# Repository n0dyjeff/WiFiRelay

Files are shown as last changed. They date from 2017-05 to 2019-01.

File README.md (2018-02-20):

# WiFiRelay - Wifi controlled dual relay
Dual relay controlled via WiFi. Uses ESP-07 module to allow external WiFi antenna.

### Motivation
This project was motivated by a desire to control my pool lights from my home automation system. I first attempted to use a Sonoff wifi controlled module with a custom hacked firmware. This would have been successful except that the unit is housed in the metallic NEMA enclosure for the pool control hardware which acted as a Faraday cage, preventing the wifi signal from reaching the Sonoff unit.

This project uses an ESP-07 module containing the ubiquitous ESP8266. The advantage of the ESP-07S is that in addition to a WiFi antenna printed onto the PC board, it has a connector allowing a coax to an external antenna, which can then be mounted outside the enclosure.

### Features
- Built in power supply allows direct connection to AC mains (85 ~ 305VAC). No external adapter required.
- Two isolated, independantly controlled, normally open relay contacts rated at 10 amps each.
- Connector for external WiFi antenna allows unit to be mounted within a metal enclosure.
- Over the air software updates.
- Wifi control via MQTT subscription.

### Software
(https://github.com/n0dyjeff/WifiRelay-Tasmota)

### Availability
All the documentation is here, but if you're not interested in building your own, I've built up a few of these and offered them on [Amazon](https://www.amazon.com/N0DY-WiFi-Controlled-Dual-Relay/dp/B072MKV8ZM), [ebay](http://www.ebay.com/itm/NEW-Web-Controlled-Dual-Relay-120-240-V-Smart-Home-Internal-External-Antenna-/152649721279), and [Tindie](https://www.tindie.com/products/n0dyjeff/wi-fi-controlled-dual-relay-wext-antenna-jack/). It's also available direct from my via my web site, [N0DY Electronics](https://www.n0dy.com).

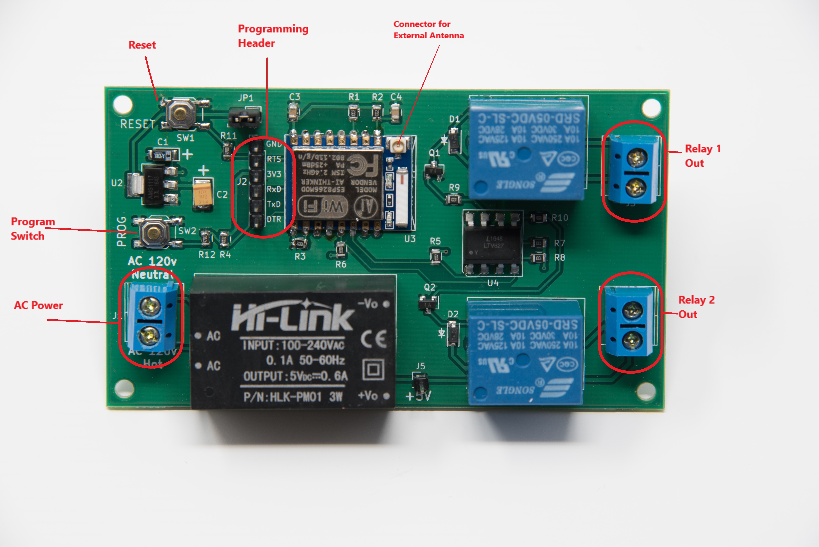
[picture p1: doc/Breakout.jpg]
Relay Board


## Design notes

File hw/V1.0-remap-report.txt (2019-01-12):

Info: Backing up file “C:\Users\jeff.DAVIS\Documents\Projects\WiFiRelay\hw\sym-lib-table” to file “C:\Users\jeff.DAVIS\Documents\Projects\WiFiRelay\hw\rescue-backup\sym-lib-table-2019-01-12-09-16-42”.
Info: Backing up file “C:\Users\jeff.DAVIS\Documents\Projects\WiFiRelay\hw\WifiRelay.sch” to file “C:\Users\jeff.DAVIS\Documents\Projects\WiFiRelay\hw\rescue-backup\WifiRelay-2019-01-12-09-16-42.sch”.
Info: Backing up file “C:\Users\jeff.DAVIS\Documents\Projects\WiFiRelay\hw\WifiRelay.pro” to file “C:\Users\jeff.DAVIS\Documents\Projects\WiFiRelay\hw\rescue-backup\WifiRelay-2019-01-12-09-16-42.pro”.
Info: Backing up file “C:\Users\jeff.DAVIS\Documents\Projects\WiFiRelay\hw\WifiRelay-cache.lib” to file “C:\Users\jeff.DAVIS\Documents\Projects\WiFiRelay\hw\rescue-backup\WifiRelay-cache-2019-01-12-09-16-42.lib”.
Info: Backing up file “C:\Users\jeff.DAVIS\Documents\Projects\WiFiRelay\hw\WifiRelay-rescue.lib” to file “C:\Users\jeff.DAVIS\Documents\Projects\WiFiRelay\hw\rescue-backup\WifiRelay-rescue-2019-01-12-09-16-42.lib”.
Info: Backing up file “C:\Users\jeff.DAVIS\Documents\Projects\WiFiRelay\hw\WifiRelay-rescue.dcm” to file “C:\Users\jeff.DAVIS\Documents\Projects\WiFiRelay\hw\rescue-backup\WifiRelay-rescue-2019-01-12-09-16-42.dcm”.
Info: Adding library “power1”, file “C:\Users\jeff.DAVIS\Documents\KiCadLibraries\library\power.lib” to project symbol library table.
Info: Adding library “device”, file “C:\Users\jeff.DAVIS\Documents\KiCadLibraries\library\device.lib” to project symbol library table.
Info: Adding library “transistors”, file “C:\Users\jeff.DAVIS\Documents\KiCadLibraries\library\transistors.lib” to project symbol library table.
Info: Adding library “conn”, file “C:\Users\jeff.DAVIS\Documents\KiCadLibraries\library\conn.lib” to project symbol library table.
Info: Adding library “linear”, file “C:\Users\jeff.DAVIS\Documents\KiCadLibraries\library\linear.lib” to project symbol library table.
Info: Adding library “regul”, file “C:\Users\jeff.DAVIS\Documents\KiCadLibraries\library\regul.lib” to project symbol library table.
Info: Adding library “74xx1”, file “C:\Users\jeff.DAVIS\Documents\KiCadLibraries\library\74xx.lib” to project symbol library table.
Info: Adding library “cmos4000”, file “C:\Users\jeff.DAVIS\Documents\KiCadLibraries\library\cmos4000.lib” to project symbol library table.
Info: Adding library “adc-dac”, file “C:\Users\jeff.DAVIS\Documents\KiCadLibraries\library\adc-dac.lib” to project symbol library table.
Info: Adding library “memory”, file “C:\Users\jeff.DAVIS\Documents\KiCadLibraries\library\memory.lib” to project symbol library table.
Info: Adding library “xilinx”, file “C:\Users\jeff.DAVIS\Documents\KiCadLibraries\library\xilinx.lib” to project symbol library table.
Info: Adding library “microcontrollers”, file “C:\Users\jeff.DAVIS\Documents\KiCadLibraries\library\microcontrollers.lib” to project symbol library table.
Info: Adding library “dsp”, file “C:\Users\jeff.DAVIS\Documents\KiCadLibraries\library\dsp.lib” to project symbol library table.
Info: Adding library “microchip”, file “C:\Users\jeff.DAVIS\Documents\KiCadLibraries\library\microchip.lib” to project symbol library table.
Info: Adding library “analog_switches”, file “C:\Users\jeff.DAVIS\Documents\KiCadLibraries\library\analog_switches.lib” to project symbol library table.
Info: Adding library “motorola”, file “C:\Users\jeff.DAVIS\Documents\KiCadLibraries\library\motorola.lib” to project symbol library table.
Info: Adding library “texas”, file “C:\Users\jeff.DAVIS\Documents\KiCadLibraries\library\texas.lib” to project symbol library table.
Info: Adding library “intel”, file “C:\Users\jeff.DAVIS\Documents\KiCadLibraries\library\intel.lib” to project symbol library table.
Info: Adding library “audio”, file “C:\Users\jeff.DAVIS\Documents\KiCadLibraries\library\audio.lib” to project symbol library table.
Info: Adding library “interface”, file “C:\Users\jeff.DAVIS\Documents\KiCadLibraries\library\interface.lib” to project symbol library table.
Info: Adding library “digital-audio”, file “C:\Users\jeff.DAVIS\Documents\KiCadLibraries\library\digital-audio.lib” to project symbol library table.
Info: Adding library “philips”, file “C:\Users\jeff.DAVIS\Documents\KiCadLibraries\library\philips.lib” to project symbol library table.
Info: Adding library “display”, file “C:\Users\jeff.DAVIS\Documents\KiCadLibraries\library\display.lib” to project symbol library table.
Info: Adding library “cypress”, file “C:\Users\jeff.DAVIS\Documents\KiCadLibraries\library\cypress.lib” to project symbol library table.
Info: Adding library “siliconi”, file “C:\Users\jeff.DAVIS\Documents\KiCadLibraries\library\siliconi.lib” to project symbol library table.
Info: Adding library “opto”, file “C:\Users\jeff.DAVIS\Documents\KiCadLibraries\library\opto.lib” to project symbol library table.
Info: Adding library “atmel”, file “C:\Users\jeff.DAVIS\Documents\KiCadLibraries\library\atmel.lib” to project symbol library table.
Info: Adding library “contrib”, file “C:\Users\jeff.DAVIS\Documents\KiCadLibraries\library\contrib.lib” to project symbol library table.
Info: Adding library “valves”, file “C:\Users\jeff.DAVIS\Documents\KiCadLibraries\library\valves.lib” to project symbol library table.
Info: Adding library “relays”, file “C:\Users\jeff.DAVIS\Documents\KiCadLibraries\library\relays.lib” to project symbol library table.
Info: Adding library “switches”, file “C:\Users\jeff.DAVIS\Documents\KiCadLibraries\library\switches.lib” to project symbol library table.
Info: Adding library “leds”, file “C:\Users\jeff.DAVIS\Documents\KiCadLibraries\library\leds.lib” to project symbol library table.
Info: Adding library “ESP8266”, file “C:\Users\jeff.DAVIS\Documents\Github\kicad-ESP8266\ESP8266.lib” to project symbol library table.
Info: Adding library “WifiRelay”, file “${KIPRJMOD}/WifiRelay.lib” to project symbol library table.
Symbol “CONN_01X06” mapped to symbol library “conn”.
Symbol “GND” mapped to symbol library “power1”.
Symbol “+3.3V” mapped to symbol library “power1”.
Symbol “+5V” mapped to symbol library “power1”.
Symbol “GND” mapped to symbol library “power1”.
Symbol “+5V” mapped to symbol library “power1”.
Symbol “+3.3V” mapped to symbol library “power1”.
Symbol “+5V” mapped to symbol library “power1”.
Symbol “CONN_01X02” mapped to symbol library “conn”.
Symbol “1N4148” mapped to symbol library “WifiRelay”.
Symbol “GND” mapped to symbol library “power1”.
Symbol “+5V” mapped to symbol library “power1”.
Symbol “+3.3V” mapped to symbol library “power1”.
Symbol “+5V” mapped to symbol library “power1”.
Symbol “+3.3V” mapped to symbol library “power1”.
Symbol “+3.3V” mapped to symbol library “power1”.
Symbol “GND” mapped to symbol library “power1”.
Symbol “GND” mapped to symbol library “power1”.
Symbol “GND” mapped to symbol library “power1”.
Symbol “C” mapped to symbol library “device”.
Symbol “GND” mapped to symbol library “power1”.
Symbol “+3.3V” mapped to symbol library “power1”.
Symbol “+3.3V” mapped to symbol library “power1”.
Symbol “PWR_FLAG” mapped to symbol library “power1”.
Symbol “PWR_FLAG” mapped to symbol library “power1”.
Symbol “R” mapped to symbol library “device”.
Symbol “R” mapped to symbol library “device”.
Symbol “R” mapped to symbol library “device”.
Symbol “R” mapped to symbol library “device”.
Symbol “MMSS8050-H” mapped to symbol library “transistors”.
Symbol “MMSS8050-H” mapped to symbol library “transistors”.
Symbol “1N4148” mapped to symbol library “WifiRelay”.
Symbol “CONN_01X02” mapped to symbol library “conn”.
Symbol “CONN_01X02” mapped to symbol library “conn”.
Symbol “IRM-02-5” mapped to symbol library “WifiRelay”.
Symbol “LM1117-3.3” mapped to symbol library “regul”.
Symbol “CP” mapped to symbol library “device”.
Symbol “CP” mapped to symbol library “device”.
Symbol “R” mapped to symbol library “device”.
Symbol “R” mapped to symbol library “device”.
Symbol “R” mapped to symbol library “device”.
Symbol “R” mapped to symbol library “device”.
Symbol “R” mapped to symbol library “device”.
Symbol “R” mapped to symbol library “device”.
Symbol “TCMT1100” mapped to symbol library “WifiRelay”.
Symbol “TCMT1100” mapped to symbol library “WifiRelay”.
Symbol “G5Q-1A” mapped to symbol library “relays”.
Symbol “G5Q-1A” mapped to symbol library “relays”.
Symbol “SW_Push” mapped to symbol library “switches”.
Symbol “SW_Push” mapped to symbol library “switches”.
Symbol “R” mapped to symbol library “device”.
Symbol “R” mapped to symbol library “device”.
Symbol “GND” mapped to symbol library “power1”.
Symbol “GND” mapped to symbol library “power1”.
Symbol “C” mapped to symbol library “device”.
Symbol “Jumper” mapped to symbol library “device”.
Symbol “PWR_FLAG” mapped to symbol library “power1”.
Symbol “LED” mapped to symbol library “device”.
Symbol “LED” mapped to symbol library “device”.
Symbol “LED” mapped to symbol library “device”.
Symbol “R” mapped to symbol library “device”.
Symbol “GND” mapped to symbol library “power1”.
Symbol “ESP-07v2” mapped to symbol library “ESP8266”.
Info: Symbol library table mapping complete!

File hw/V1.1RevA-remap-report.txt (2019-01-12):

Info: Backing up file “C:\Users\jeff.DAVIS\Documents\Projects\WiFiRelay\hw\sym-lib-table” to file “C:\Users\jeff.DAVIS\Documents\Projects\WiFiRelay\hw\rescue-backup\sym-lib-table-2019-01-12-10-57-47”.
Info: Backing up file “C:\Users\jeff.DAVIS\Documents\Projects\WiFiRelay\hw\WifiRelay.sch” to file “C:\Users\jeff.DAVIS\Documents\Projects\WiFiRelay\hw\rescue-backup\WifiRelay-2019-01-12-10-57-47.sch”.
Info: Backing up file “C:\Users\jeff.DAVIS\Documents\Projects\WiFiRelay\hw\WifiRelay.pro” to file “C:\Users\jeff.DAVIS\Documents\Projects\WiFiRelay\hw\rescue-backup\WifiRelay-2019-01-12-10-57-47.pro”.
Info: Backing up file “C:\Users\jeff.DAVIS\Documents\Projects\WiFiRelay\hw\WifiRelay-cache.lib” to file “C:\Users\jeff.DAVIS\Documents\Projects\WiFiRelay\hw\rescue-backup\WifiRelay-cache-2019-01-12-10-57-47.lib”.
Info: Backing up file “C:\Users\jeff.DAVIS\Documents\Projects\WiFiRelay\hw\WifiRelay-rescue.lib” to file “C:\Users\jeff.DAVIS\Documents\Projects\WiFiRelay\hw\rescue-backup\WifiRelay-rescue-2019-01-12-10-57-47.lib”.
Info: Backing up file “C:\Users\jeff.DAVIS\Documents\Projects\WiFiRelay\hw\WifiRelay-rescue.dcm” to file “C:\Users\jeff.DAVIS\Documents\Projects\WiFiRelay\hw\rescue-backup\WifiRelay-rescue-2019-01-12-10-57-47.dcm”.
Info: Adding library “power1”, file “C:\Users\jeff.DAVIS\Documents\KiCadLibraries\library\power.lib” to project symbol library table.
Info: Adding library “device”, file “C:\Users\jeff.DAVIS\Documents\KiCadLibraries\library\device.lib” to project symbol library table.
Info: Adding library “transistors”, file “C:\Users\jeff.DAVIS\Documents\KiCadLibraries\library\transistors.lib” to project symbol library table.
Info: Adding library “conn”, file “C:\Users\jeff.DAVIS\Documents\KiCadLibraries\library\conn.lib” to project symbol library table.
Info: Adding library “linear”, file “C:\Users\jeff.DAVIS\Documents\KiCadLibraries\library\linear.lib” to project symbol library table.
Info: Adding library “regul”, file “C:\Users\jeff.DAVIS\Documents\KiCadLibraries\library\regul.lib” to project symbol library table.
Info: Adding library “74xx1”, file “C:\Users\jeff.DAVIS\Documents\KiCadLibraries\library\74xx.lib” to project symbol library table.
Info: Adding library “cmos4000”, file “C:\Users\jeff.DAVIS\Documents\KiCadLibraries\library\cmos4000.lib” to project symbol library table.
Info: Adding library “adc-dac”, file “C:\Users\jeff.DAVIS\Documents\KiCadLibraries\library\adc-dac.lib” to project symbol library table.
Info: Adding library “memory”, file “C:\Users\jeff.DAVIS\Documents\KiCadLibraries\library\memory.lib” to project symbol library table.
Info: Adding library “xilinx”, file “C:\Users\jeff.DAVIS\Documents\KiCadLibraries\library\xilinx.lib” to project symbol library table.
Info: Adding library “microcontrollers”, file “C:\Users\jeff.DAVIS\Documents\KiCadLibraries\library\microcontrollers.lib” to project symbol library table.
Info: Adding library “dsp”, file “C:\Users\jeff.DAVIS\Documents\KiCadLibraries\library\dsp.lib” to project symbol library table.
Info: Adding library “microchip”, file “C:\Users\jeff.DAVIS\Documents\KiCadLibraries\library\microchip.lib” to project symbol library table.
Info: Adding library “analog_switches”, file “C:\Users\jeff.DAVIS\Documents\KiCadLibraries\library\analog_switches.lib” to project symbol library table.
Info: Adding library “motorola”, file “C:\Users\jeff.DAVIS\Documents\KiCadLibraries\library\motorola.lib” to project symbol library table.
Info: Adding library “texas”, file “C:\Users\jeff.DAVIS\Documents\KiCadLibraries\library\texas.lib” to project symbol library table.
Info: Adding library “intel”, file “C:\Users\jeff.DAVIS\Documents\KiCadLibraries\library\intel.lib” to project symbol library table.
Info: Adding library “audio”, file “C:\Users\jeff.DAVIS\Documents\KiCadLibraries\library\audio.lib” to project symbol library table.
Info: Adding library “interface”, file “C:\Users\jeff.DAVIS\Documents\KiCadLibraries\library\interface.lib” to project symbol library table.
Info: Adding library “digital-audio”, file “C:\Users\jeff.DAVIS\Documents\KiCadLibraries\library\digital-audio.lib” to project symbol library table.
Info: Adding library “philips”, file “C:\Users\jeff.DAVIS\Documents\KiCadLibraries\library\philips.lib” to project symbol library table.
Info: Adding library “display”, file “C:\Users\jeff.DAVIS\Documents\KiCadLibraries\library\display.lib” to project symbol library table.
Info: Adding library “cypress”, file “C:\Users\jeff.DAVIS\Documents\KiCadLibraries\library\cypress.lib” to project symbol library table.
Info: Adding library “siliconi”, file “C:\Users\jeff.DAVIS\Documents\KiCadLibraries\library\siliconi.lib” to project symbol library table.
Info: Adding library “opto”, file “C:\Users\jeff.DAVIS\Documents\KiCadLibraries\library\opto.lib” to project symbol library table.
Info: Adding library “atmel”, file “C:\Users\jeff.DAVIS\Documents\KiCadLibraries\library\atmel.lib” to project symbol library table.
Info: Adding library “contrib”, file “C:\Users\jeff.DAVIS\Documents\KiCadLibraries\library\contrib.lib” to project symbol library table.
Info: Adding library “valves”, file “C:\Users\jeff.DAVIS\Documents\KiCadLibraries\library\valves.lib” to project symbol library table.
Info: Adding library “relays”, file “C:\Users\jeff.DAVIS\Documents\KiCadLibraries\library\relays.lib” to project symbol library table.
Info: Adding library “switches”, file “C:\Users\jeff.DAVIS\Documents\KiCadLibraries\library\switches.lib” to project symbol library table.
Info: Adding library “leds”, file “C:\Users\jeff.DAVIS\Documents\KiCadLibraries\library\leds.lib” to project symbol library table.
Info: Adding library “ESP8266”, file “C:\Users\jeff.DAVIS\Documents\GitHub\kicad-ESP8266\ESP8266.lib” to project symbol library table.
Info: Adding library “WifiRelay”, file “${KIPRJMOD}/WifiRelay.lib” to project symbol library table.
Symbol “CONN_01X06” mapped to symbol library “conn”.
Symbol “GND” mapped to symbol library “power1”.
Symbol “+5V” mapped to symbol library “power1”.
Symbol “GND” mapped to symbol library “power1”.
Symbol “+5V” mapped to symbol library “power1”.
Symbol “+3.3V” mapped to symbol library “power1”.
Symbol “+5V” mapped to symbol library “power1”.
Symbol “CONN_01X02” mapped to symbol library “conn”.
Symbol “1N4148” mapped to symbol library “WifiRelay”.
Symbol “GND” mapped to symbol library “power1”.
Symbol “+5V” mapped to symbol library “power1”.
Symbol “+3.3V” mapped to symbol library “power1”.
Symbol “+5V” mapped to symbol library “power1”.
Symbol “+3.3V” mapped to symbol library “power1”.
Symbol “GND” mapped to symbol library “power1”.
Symbol “GND” mapped to symbol library “power1”.
Symbol “GND” mapped to symbol library “power1”.
Symbol “C” mapped to symbol library “device”.
Symbol “GND” mapped to symbol library “power1”.
Symbol “+3.3V” mapped to symbol library “power1”.
Symbol “+3.3V” mapped to symbol library “power1”.
Symbol “PWR_FLAG” mapped to symbol library “power1”.
Symbol “PWR_FLAG” mapped to symbol library “power1”.
Symbol “R” mapped to symbol library “device”.
Symbol “R” mapped to symbol library “device”.
Symbol “R” mapped to symbol library “device”.
Symbol “R” mapped to symbol library “device”.
Symbol “MMSS8050-H” mapped to symbol library “transistors”.
Symbol “MMSS8050-H” mapped to symbol library “transistors”.
Symbol “1N4148” mapped to symbol library “WifiRelay”.
Symbol “CONN_01X02” mapped to symbol library “conn”.
Symbol “CONN_01X02” mapped to symbol library “conn”.
Symbol “IRM-02-5” mapped to symbol library “WifiRelay”.
Symbol “LM1117-3.3” mapped to symbol library “regul”.
Symbol “CP” mapped to symbol library “device”.
Symbol “CP” mapped to symbol library “device”.
Symbol “R” mapped to symbol library “device”.
Symbol “R” mapped to symbol library “device”.
Symbol “R” mapped to symbol library “device”.
Symbol “R” mapped to symbol library “device”.
Symbol “R” mapped to symbol library “device”.
Symbol “R” mapped to symbol library “device”.
Symbol “SW_Push” mapped to symbol library “switches”.
Symbol “SW_Push” mapped to symbol library “switches”.
Symbol “R” mapped to symbol library “device”.
Symbol “R” mapped to symbol library “device”.
Symbol “GND” mapped to symbol library “power1”.
Symbol “GND” mapped to symbol library “power1”.
Symbol “C” mapped to symbol library “device”.
Symbol “ESP-07v2” mapped to symbol library “ESP8266”.
Symbol “Songle-SRD-05VDC-SL-C” mapped to symbol library “WifiRelay”.
Symbol “Songle-SRD-05VDC-SL-C” mapped to symbol library “WifiRelay”.
Symbol “+3.3V” mapped to symbol library “power1”.
Symbol “PC827” mapped to symbol library “opto”.
Symbol “PC827” mapped to symbol library “opto”.
Symbol “TEST_1P” mapped to symbol library “conn”.
Symbol “TEST_1P” mapped to symbol library “conn”.
Symbol “Jumper_Dual” mapped to symbol library “WifiRelay”.
Symbol “PWR_FLAG” mapped to symbol library “power1”.
Info: Symbol library table mapping complete!

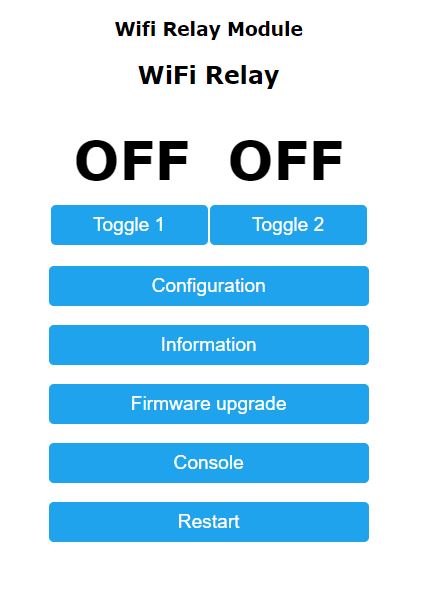
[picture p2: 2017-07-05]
doc/Main Menu.JPG

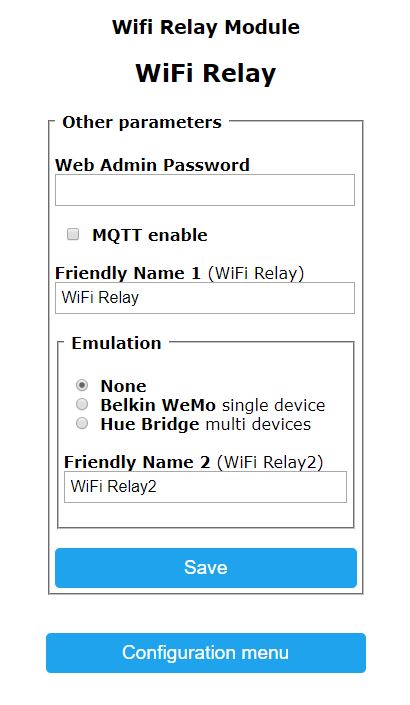
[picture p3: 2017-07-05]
doc/MQTT Enable.jpg

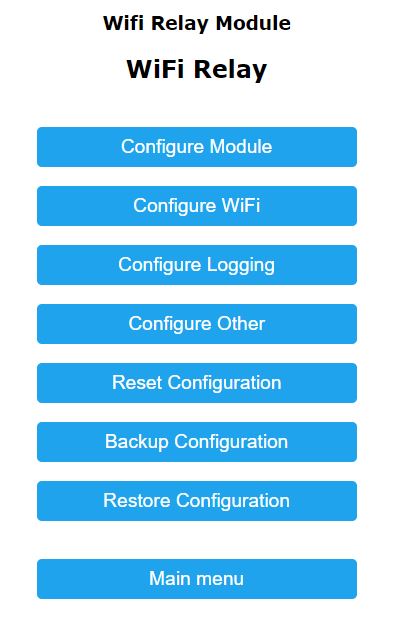
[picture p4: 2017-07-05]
doc/Configuration Menu.jpg

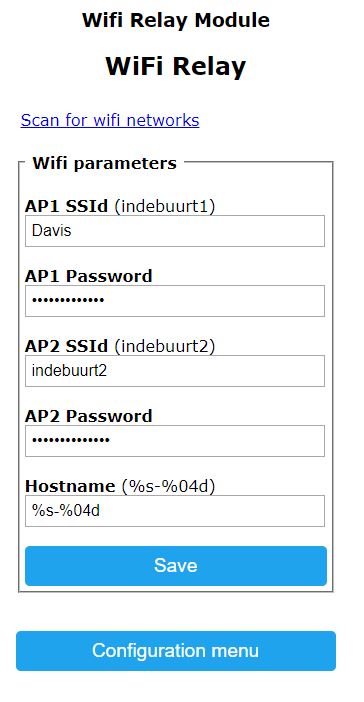
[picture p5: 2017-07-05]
doc/Wifi Menu.JPG

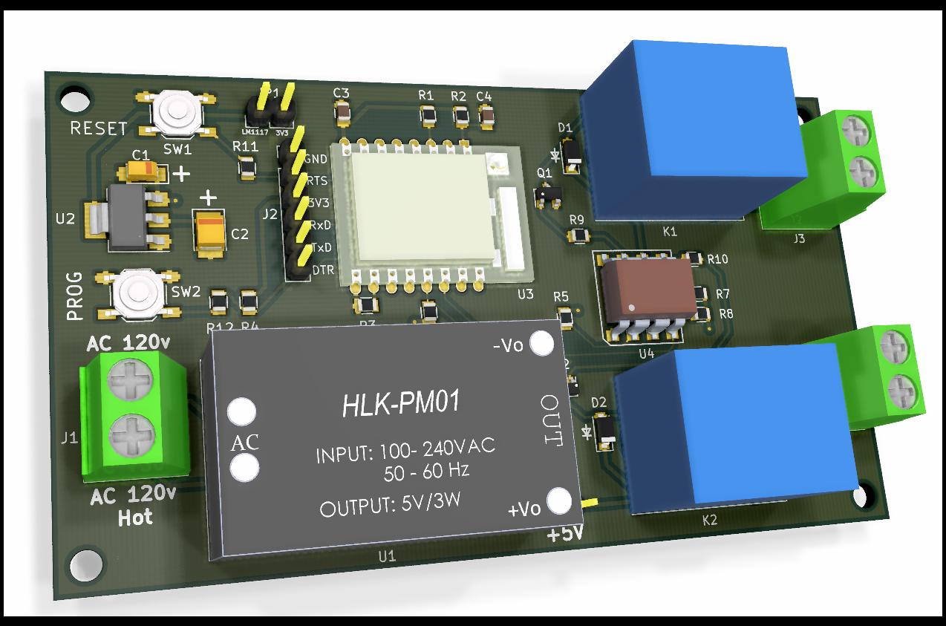
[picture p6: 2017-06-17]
hw/WifiRelay.jpg

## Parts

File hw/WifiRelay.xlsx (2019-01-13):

Source: | C:\Users\jeff.DAVIS\Documents\Projects\WiFiRelay\hw\WifiRelay.sch
Date: | 2019-12-01 16:21
Tool: | Eeschema (5.0.2)-1
Component Count: | 35
Ref | Value | Footprint | Datasheet | Manufacturer | Vendor
C1 | 10 uF | Capacitors_Tantalum_SMD:CP_Tantalum_Case-A_EIA-3216-18_Reflow | http://www.vishay.com/docs/40002/293d.pdf
C2 | 100 uF | Capacitors_Tantalum_SMD:CP_Tantalum_Case-B_EIA-3528-21_Reflow | http://www.vishay.com/docs/40156/tl8.pdf
C3 | 100nF | Capacitors_SMD:C_0805 | http://www.mouser.com/ds/2/212/KEM_C1002_X7R_SMD-357932.pdf
C4 | 100nF | Capacitors_SMD:C_0805 | http://www.mouser.com/ds/2/212/KEM_C1002_X7R_SMD-357932.pdf
D1 | 1N4148 | Diodes_SMD:D_SOD-123 | https://www.diodes.com/assets/Datasheets/ds30086.pdf
D2 | 1N4148 | Diodes_SMD:D_SOD-123 | https://www.diodes.com/assets/Datasheets/ds30086.pdf
J1 | CONN_01X02 | Connectors_Terminal_Blocks:TerminalBlock_Pheonix_MKDS1.5-2pol
J2 | CONN_01X06 | Pin_Headers:Pin_Header_Straight_1x06_Pitch2.54mm
J3 | CONN_01X02 | Connectors_Terminal_Blocks:TerminalBlock_Pheonix_MKDS1.5-2pol
J4 | CONN_01X02 | Connectors_Terminal_Blocks:TerminalBlock_Pheonix_MKDS1.5-2pol
J5 | TEST_1P | Pin_Headers:Pin_Header_Straight_1x01_Pitch2.54mm
J6 | TEST_1P | Pin_Headers:Pin_Header_Straight_1x01_Pitch2.54mm
JP1 | Jumper_Dual | Pin_Headers:Pin_Header_Straight_1x03_Pitch2.54mm
K1 | Songle-SRD-05VDC-SL-C | Relays_THT:Relay_SPDT_SANYOU_SRD_Series_Form_C
K2 | Songle-SRD-05VDC-SL-C | Relays_THT:Relay_SPDT_SANYOU_SRD_Series_Form_C
Q1 | MMSS8050-H | TO_SOT_Packages_SMD:SOT-23
Q2 | MMSS8050-H | TO_SOT_Packages_SMD:SOT-23
R1 | 10K | Resistors_SMD:R_0805 | http://www.mouser.com/ds/2/418/NG_CD_1623097_BA-655653.pdf
R2 | 10K | Resistors_SMD:R_0805 | http://www.mouser.com/ds/2/418/NG_CD_1623097_BA-655653.pdf
R3 | 10K | Resistors_SMD:R_0805 | http://www.mouser.com/ds/2/418/NG_CD_1623097_BA-655653.pdf
R4 | 10K | Resistors_SMD:R_0805 | http://www.mouser.com/ds/2/418/NG_CD_1623097_BA-655653.pdf
R5 | 10K | Resistors_SMD:R_0805 | http://www.mouser.com/ds/2/418/NG_CD_1623097_BA-655653.pdf
R6 | 10K | Resistors_SMD:R_0805 | http://www.mouser.com/ds/2/418/NG_CD_1623097_BA-655653.pdf
R7 | 1K | Resistors_SMD:R_0805 | http://www.te.com/commerce/DocumentDelivery/DDEController?Action=showdoc
R8 | 1K | Resistors_SMD:R_0805 | http://www.te.com/commerce/DocumentDelivery/DDEController?Action=showdoc
R9 | 1K | Resistors_SMD:R_0805
R10 | 1K | Resistors_SMD:R_0805
R11 | 470 | Resistors_SMD:R_0805 | http://www.te.com/commerce/DocumentDelivery/DDEController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
R12 | 470 | Resistors_SMD:R_0805 | http://www.te.com/commerce/DocumentDelivery/DDEController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
SW1 | SW_Push | Buttons_Switches_SMD:SW_SPST_TL3342 | http://www.omron.com/ecb/products/pdf/en-b3u.pdf
SW2 | SW_Push | Buttons_Switches_SMD:SW_SPST_TL3342 | http://www.omron.com/ecb/products/pdf/en-b3u.pdf
U1 | HLK-PM01 | WifiRelay:HLK-PM01 | http://www.hlktech.net/product_detail.php?ProId=54
U2 | LM1117-3.3 | TO_SOT_Packages_SMD:SOT-223-3Lead_TabPin2
U3 | ESP-07v2 | ESP8266:ESP-07v2
U4 | PC827 | WifiRelay:SOIC-8

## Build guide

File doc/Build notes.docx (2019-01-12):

Build notes:

- Some extra solder paste on the ESP-07 pins might be useful. Try using a toothpick to manually add a small amount to each pin, or at least to the pins in use.
- Markings on the diodes correspond to the cathode, which is the straight line on the diode schematic symbol. So the line on the diode corresponds to the line on the diode schematic.
- Some extra solder might be useful on the two diodes – seems like the pads are too far separated. [2019-01-02] Found that there are two different footprints of 1N4148 diode. One is SOD-123 (correct), and the other is SOD-323 (too small for pad spacing).
- When attempting to solder the back side of the pin headers, try pushing a jumper onto the pin header to keep it snug to the board when inverting it to solder.

Test / troubleshooting:

- I needed to have a wifi antenna attached to be able to connect. Haven’t thoroughly understood this yet. [2018-12-31] Issue occurs even when not sitting on a conductive static bag. May be unique to module.
- Don’t expect “AT” commands to work with the original firmware. It’s sufficient if you are getting serial data out and the keyboard inputs can be seen echoed. If you see that, then both TX and RX serial are working.
- Use these settings rather than the ones on the arendts github site – they’re for Sonoff, not necessarily an EPS-07.

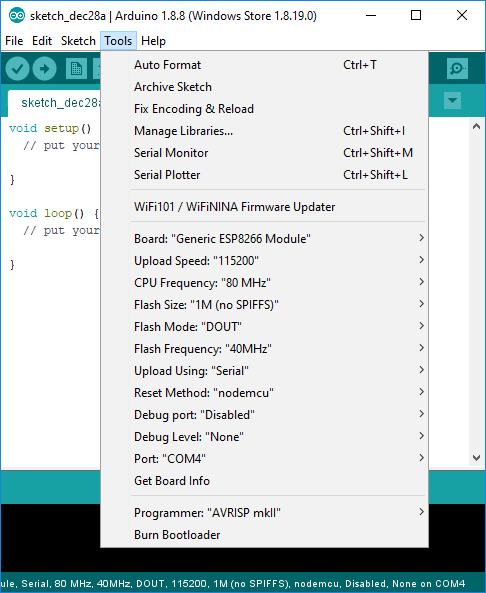
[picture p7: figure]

- Make sure the reset method is “nodemcu”
- WiFi might not connect immediately after downloading. May need to unplug.

Tool Chain Notes

- Arduino 1.8.8 board packages are in Documents/ArduinoData
- OTA upload directory is subdirectory of the api directory: /var/www/html/api/Arduino
- Permissions need to have group write by www-data
- OTA server is uranus.davis.local. Need full DNS name.
- Need python installed at Windows level, not just in Ubuntu subsystem
- Ended up with Python 2.7.15, due to incompatibilities of pyCurl with 3.7.0. Pycurl must also be installed, pip install pycurl if the MSVCRT version of python is compatible with a wheel version of pycurl.
- Board package 2.4.2 seems to have an issue with DNS GetHostByName function. DNS works OK with 2.3.0, so reverted to that board package. [2018-12-31] DNS issue is that when decoding “.local” addresses, an mDNS message is sent rather than an ordinary DNS message. And there doesn’t appear to be any fallback to trying traditional DNS if no response on mDNS. Workaround for now is to hard-code IP addresses for MQTT, syslog, and OTA servers.
- To set up OTA in Arduino
  - Copy boards.txt and packages.txt from correct board version folder (e.g. 2.4.2) into packages\esp8266\hardware\esp8266\2.4.2
  - Copy espupload.py to packages\esp8266\hardware\esp8266\2.3.0\tools.
  - Edit HOST_ADDR in espupload.py to server address where api/arduino directory is located (uranus.davis.local)

# Verbose Output from Successful Upload

PS C:\Users\jeff.DAVIS\Documents\Projects\WiFiRelay\sw\BoardTest> C:\Users\jeff.DAVIS\Documents\ArduinoData\packages\esp8266\tools\esptool\0.4.9\esptool.exe -cp COM4 -cb 115200 -cd nodemcu -ca 0x0 -bz 1M -bm dout -cf .\BoardTest.ino.bin -vv

esptool v0.4.9 - (c) 2014 Ch. Klippel <ck@atelier-klippel.de>

setting port from COM1 to COM4

setting baudrate from 115200 to 115200

setting board to nodemcu

setting address from 0x00000000 to 0x00000000

setting flash size from 512K to 1M

setting flash mode from qio to dout

espcomm_upload_file

espcomm_upload_mem

setting serial port timeouts to 1000 ms

opening bootloader

resetting board

trying to connect

flush start

setting serial port timeouts to 1 ms

setting serial port timeouts to 1000 ms

flush complete

espcomm_send_command: sending command header

espcomm_send_command: sending command payload

read 0, requested 1

trying to connect

flush start

setting serial port timeouts to 1 ms

setting serial port timeouts to 1000 ms

flush complete

espcomm_send_command: sending command header

espcomm_send_command: sending command payload

espcomm_send_command: receiving 2 bytes of data

espcomm_send_command: receiving 2 bytes of data

espcomm_send_command: receiving 2 bytes of data

espcomm_send_command: receiving 2 bytes of data

espcomm_send_command: receiving 2 bytes of data

espcomm_send_command: receiving 2 bytes of data

espcomm_send_command: receiving 2 bytes of data

espcomm_send_command: receiving 2 bytes of data

Uploading 239328 bytes from .\BoardTest.ino.bin to flash at 0x00000000

erasing flash

size: 03a6e0 address: 000000

first_sector_index: 0

total_sector_count: 59

head_sector_count: 16

adjusted_sector_count: 43

erase_size: 02b000

espcomm_send_command: sending command header

espcomm_send_command: sending command payload

setting serial port timeouts to 15000 ms

setting serial port timeouts to 1000 ms

espcomm_send_command: receiving 2 bytes of data

writing flash

................................................................................ [ 34% ]

................................................................................ [ 68% ]

.......................................................................... [ 100% ]

starting app without reboot

espcomm_send_command: sending command header

espcomm_send_command: sending command payload

espcomm_send_command: receiving 2 bytes of data

closing bootloader

flush start

setting serial port timeouts to 1 ms

setting serial port timeouts to 1000 ms

flush complete

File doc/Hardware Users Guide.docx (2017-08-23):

# N0DY Wi-Fi Relay Hardware User’s Guide


Figure 1-Hardware Breakout

AC Power

Input connector for primary AC power. The N0DY Wi-Fi Relay works with alternating current 100 – 240 volts, 50-60 Hz. Exercise caution as the pins for the connector and the power module are exposed on the bottom side of the board, creating the potential for shock and short circuits.

Relay 1 Out, Relay 2 Out

Output connectors for the two controlled relays. The relay contacts are rated for 10A non inductive loads up to 240 volts AC.

Connector for External Antenna

U.FL male connector can be used to connect a cable for an external antenna. This is useful if additional range is needed or if the N0DY Wi-Fi Relay will be mounted inside a metal enclosure. Both the built in antenna and the external antenna can be connected simultaneously if desired.

3.3V Power Jumper

This jumper allows the processor and 3.3v circuits to be powered either from the AC / DC converter (normal case), or through the 3.3v pin on the programming header (used when flashing the processor). If your FTDI device supplies 3.3v power, remove the jumper to disconnect from the onboard power supply. For normal operation, connect the pins.

Programming Header

This header allows access to various signals useful for flashing the ESP8266 device, communicating over serial ports, providing 3.3v power, and GPIO 0. All pins are labelled according to their function on the N0DY WI-FI RELAY.

GND – Ground reference.

RTS – Connects to ESP8266 RESET and RESET switch. Frequently used to connect to an RTS signal for flashing from an Arduino IDE.

3V3 – Used to supply 3.3 volt power to the board when programming. Set the 3.3v power jumper appropriately when using this pin, and disconnect AC power.

RXD – Connects to the ESP8266 serial transmit data pin. Connect this pin to the RxD of an FTDI device. Normally 115,200 bits/sec.

TXD – Connects to the ESP8266 serial receive data pin. Connect this pin to the TxD of an FTDI device. Normally 115,200 bits/sec.

DTR – Connects to ESP8266 GPIO 0 and the PROG switch. Frequently used to connect to a DTR signal for flashing from an Arduino IDE. Can also be used as a general purpose IO pin.

Program Switch

Connects to the ESP8266 GPIO 0. Used for multiple purposes.

Flashing – Holding down the PROG button while simultaneously pushing and releasing the RESET button puts the ESP8266 into programming mode. This is a manual alternative to using the RTS / DTR combination with an Arduino IDE style flashing program.

1 short press: Toggles Relay 1. If MQTT is configured (see Quick Start Guide) sends a MQTT status message like stat/wifirelay/LIGHT on. If cmnd/wifirelay/ButtonRetain on has been used the MQTT message will also contain the MQTT retain flag.

2 short presses: Toggles Relay 2 and sends a MQTT status message like stat/wifirelay/POWER on.

3 short presses: Start Wifi SmartConfig allowing for SSID and Password configuration using an Android mobile phone with the ESP8266 SmartConfig app. The MQTT server still needs to be configured in the user_config.h file. A single button press during this period will abort and restart.

4 short presses: Start Wifi manager providing an Access Point with IP address 192.168.4.1 and a web server allowing the configuration of both Wifi and MQTT parameters. A single button press during this period will abort and restart.

5 short presses: Start Wifi Protected Setup (WPS) allowing for SSID and Password configuration using the router’s WPS button or webpage. A single button press during this period will abort and restart.

6 short presses: Will restart the module

7 short presses: Start Over The Air download of firmware. See software documentation at https://github.com/n0dyjeff/WifiRelay-Tasmota for details on how to set this up.

Pressing the button for over four seconds: Reset settings to defaults and restarts the device.

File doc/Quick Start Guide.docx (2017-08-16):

# Quick Start Guide – How to connect to your Wi-Fi network

Overview: We’re going to connect the N0DY Wi-Fi Relay to AC power. It will start up a standalone wireless access point and a standalone web site. We’ll use the access point to make the initial connection to the N0DY Wi-Fi Relay. Connecting your browser to the web site will allow you to configure the N0DY Wi-Fi Relay for your specific Wi-Fi setup.

1. Connect 120v AC power to the single terminal block labelled “J1”. CAUTION: Mains voltages are hazardous and potentially lethal. Do not allow it to come into contact with your body. Do not allow the board traces carrying the AC power to the AC/DC converter to come into contact with other conductors, potentially causing a short circuit. The N0DY Wi-Fi Relay can work with AC input voltages ranging from 100 – 240 VAC.

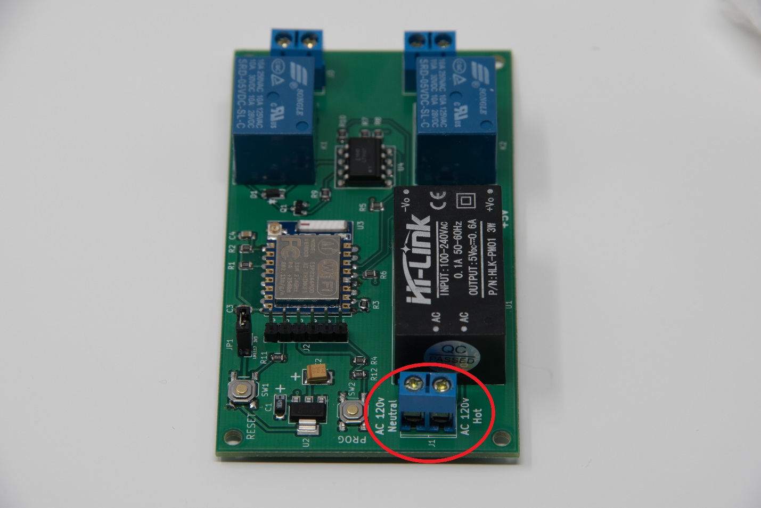
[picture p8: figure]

2. The onboard processor (ESP-8266) will start up a standalone Wi-Fi access point (AP), which will allow you make the initial connection to the N0DY Wi-Fi Relay. The standalone AP will have a name starting with “wifirelay-####”. Use your phone or laptop to find the access point and connect to it.
3. Once connected to the access point’s network, access the web page at http://192.168.4.1. (It may start up automatically on the Wi-Fi configuration page after connecting). The web server will provide you with buttons to control the state of both relays, menus to configure the device, and provide status and logging information.


4. To connect the N0DY Wi-Fi Relay to your home Wi-Fi, go to the Configuration menu, and select the Configure Wi-Fi menu item. There you will find a link to click to scan for available Wi-Fi networks. There are places to make entries for two Wi-Fi access points (APs) (although only one is needed – the second is a backup). Enter your network’s SSID and password in the fields provided. You can also give your N0DY Wi-Fi Relay a hostname to use to refer to it. The default is the same as the access point name used earlier, “wifirelay-####”, where # represents decimal digits.   Before you hit save, be aware that you’ll need to be able to find the IP address that gets assigned to your N0DY Wi-Fi Relay in order to be able to communicate with it. This is highly dependent on how you have your network set up. You might be able to refer to it simply with the hostname you provided in the Wi-Fi configuration, as in http://your-hostname-here. In other cases, you might have to check your Wi-Fi router/WAP to see what IP address was assigned. If you go this route, you can access the N0DY Wi-Fi Relay with http://your-ip-address-here.


5. Click Save. You’ll then need to reconnect by pointing your web browser to one of the address forms discussed in the previous step. Once this is done, your N0DY Wi-Fi Relay is controllable via its web page over your Wi-Fi network. You can now turn on and turn off the two on-board relays by means of the device’s web page.

MQTT is disabled by default. If you have access to an MQTT server, use the “Other” configuration page and select the Enable MQTT option. This will then restart the module and a new MQTT Configuration option will become available.


This is a very basic setup. There are many, many more capabilities of the N0DY Wi-Fi relay. For complete documentation, see the project site on GitHub, https://github.com/n0dyjeff/WiFiRelay for hardware, and https://github.com/n0dyjeff/WifiRelay-Tasmota for software.

Questions? Help Needed? Contact Me!

jeff@n0dy.com

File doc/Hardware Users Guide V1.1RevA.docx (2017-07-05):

# N0DY Wi-Fi Relay Hardware User’s Guide

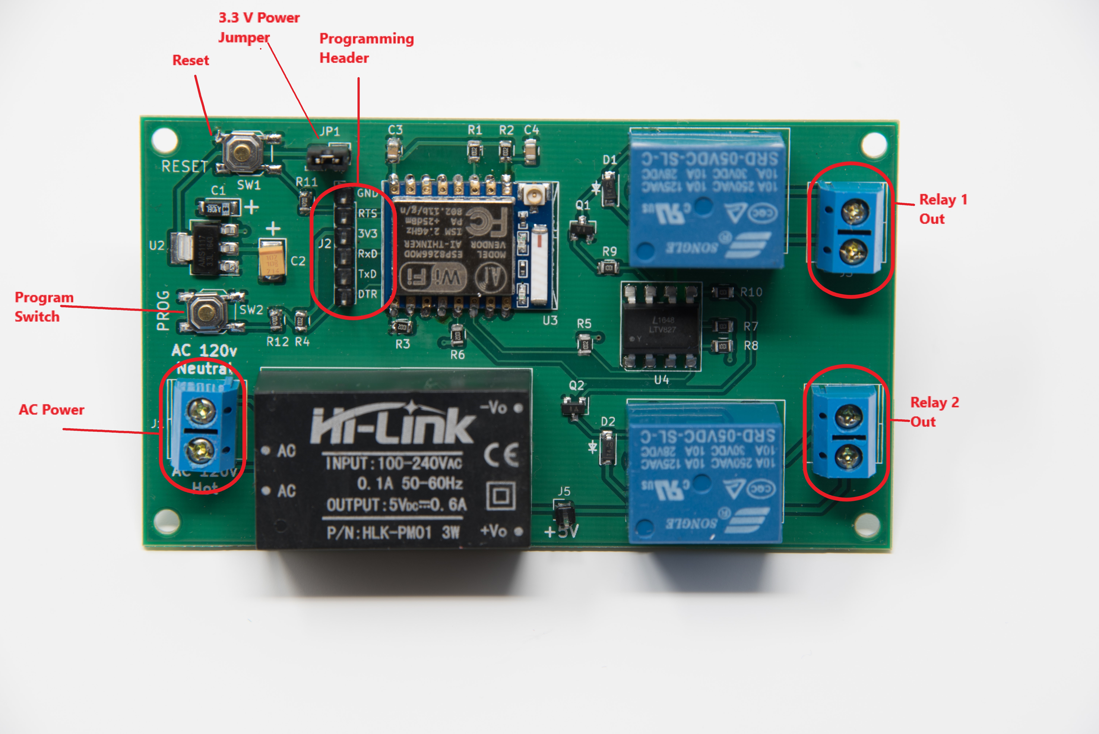
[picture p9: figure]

Figure 1-Hardware Breakout

AC Power

Input connector for primary AC power. The DEVICE_NAME works with alternating current 100 – 240 volts, 50-60 Hz. Exercise caution as the pins for the connector and the power module are exposed on the bottom side of the board, creating the potential for shock and short circuits.

Relay 1 Out, Relay 2 Out

Output connectors for the two controlled relays. The relay contacts are rated for 10A non inductive loads up to 240 volts AC.

3.3V Power Jumper

This jumper allows the processor and 3.3v circuits to be powered either from the AC / DC converter (normal case), or through the 3.3v pin on the programming header (used when flashing the processor). If your FTDI device supplies 3.3v power, move the jumper to connect the pins labelled “3V3” and “USB” and disconnect the DEVICE_NAME from AC power. For normal operation, connect the pins labelled “3V3” and “LM1117”.

Programming Header

This header allows access to various signals useful for flashing the ESP8266 device, communicating over serial ports, providing 3.3v power, and GPIO 0. All pins are labelled according to their function on the DEVICE_NAME.

GND – Ground reference.

RESET – Connects to ESP8266 RESET and RESET switch. Frequently used to connect to an RTS signal for flashing from an Arduino IDE.

3V3 – Used to supply 3.3 volt power to the board when programming. Set the 3.3v power jumper appropriately when using this pin, and disconnect AC power.

TXD – Connects to the ESP8266 serial transmit data pin. Connect this pin to the RxD of an FTDI device. Normally 115,200 bits/sec.

RXD – Connects to the ESP8266 serial receive data pin. Connect this pin to the TxD of an FTDI device. Normally 115,200 bits/sec.

GPIO 0 – Connects to ESP8266 GPIO 0 and the PROG switch. Frequently used to connect to a DTR signal for flashing from an Arduino IDE. Can also be used as a general purpose IO pin. See “Hacking the N0DY Wi-Fi Relay” for details.

Program Switch

Connects to the ESP8266 GPIO 0. Used for multiple purposes.

Flashing – Holding down the PROG button while simultaneously pushing and releasing the RESET button puts the ESP8266 into programming mode. This is a manual alternative to using the RTS / DTR combination with an Arduino IDE style flashing program.

<TODO CHECK>1 short press: Toggles Relay 1. If MQTT is configured (see SOFTWARE_GUIDE) sends a MQTT status message like stat/sonoff/LIGHT on. If cmnd/sonoff/ButtonRetain on has been used the MQTT message will also contain the MQTT retain flag.

<TODO CHECK>2 short presses: Toggles Relay 2. This will blink the LED twice and sends a MQTT status message like stat/sonoff/POWER on.

<TODO CHECK>3 short presses: Start Wifi smartconfig allowing for SSID and Password configuration using an Android mobile phone with the ESP8266 SmartConfig app. The MQTT server still needs to be configured in the user_config.h file. The LED will blink during the config period. A single button press during this period will abort and restart sonoff.

4 short presses: Start Wifi manager providing an Access Point with IP address 192.168.4.1 and a web server allowing the configuration of both Wifi and MQTT parameters. A single button press during this period will abort and restart sonoff.

5 short presses: Start Wifi Protected Setup (WPS) allowing for SSID and Password configuration using the routers WPS button or webpage. A single button press during this period will abort and restart sonoff.

6 short presses: Will restart the module

7 short presses: Start OTA download of firmware.

Pressing the button for over four seconds: Reset settings to defaults as defined in user_config.h and restarts the device

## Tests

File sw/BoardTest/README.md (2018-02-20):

# Board Test Software 
Code for initial checkout of a newly built board.

### Private password example files
Copy the files "PrivateMQTT.example" and "PrivateWifi.example" to "PrivateMQTT.h" and "PrivateWifi.h", respectively. Edit these files to set the correct server, username, password, SSID, etc. for your installation

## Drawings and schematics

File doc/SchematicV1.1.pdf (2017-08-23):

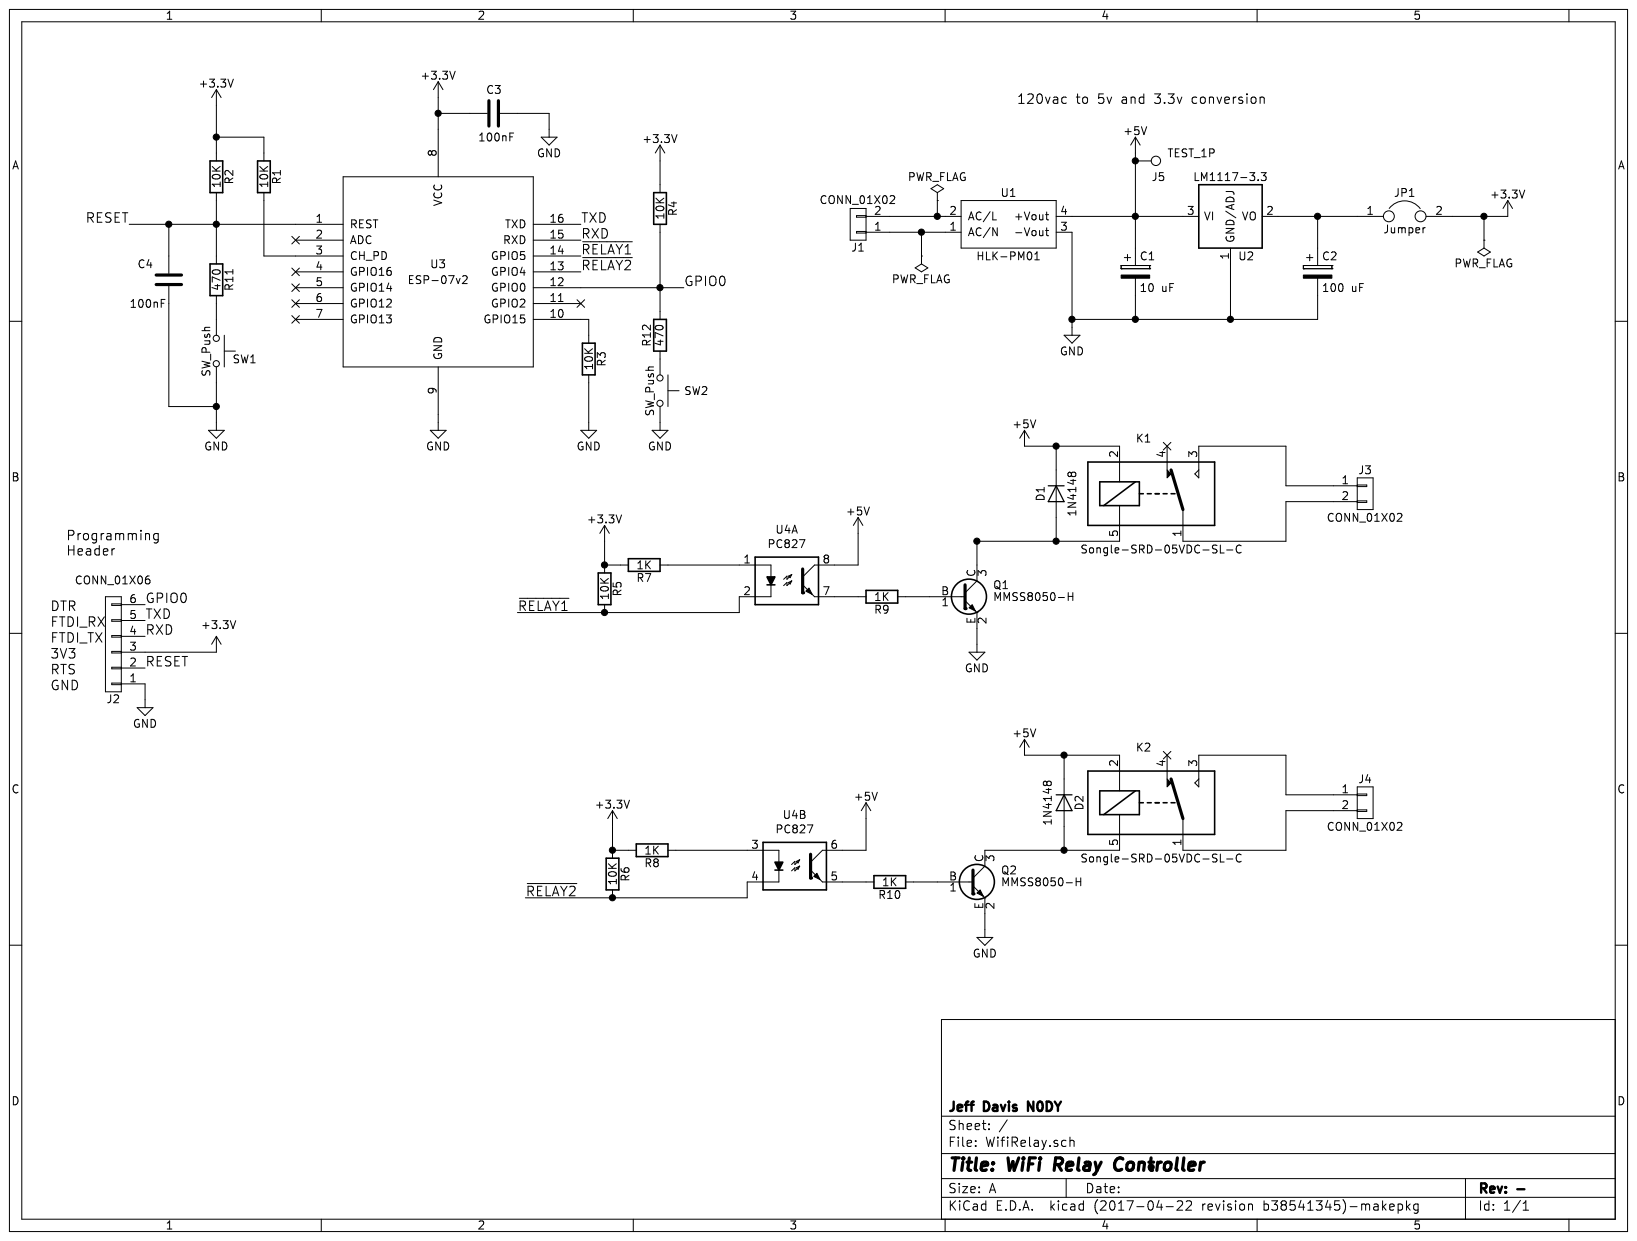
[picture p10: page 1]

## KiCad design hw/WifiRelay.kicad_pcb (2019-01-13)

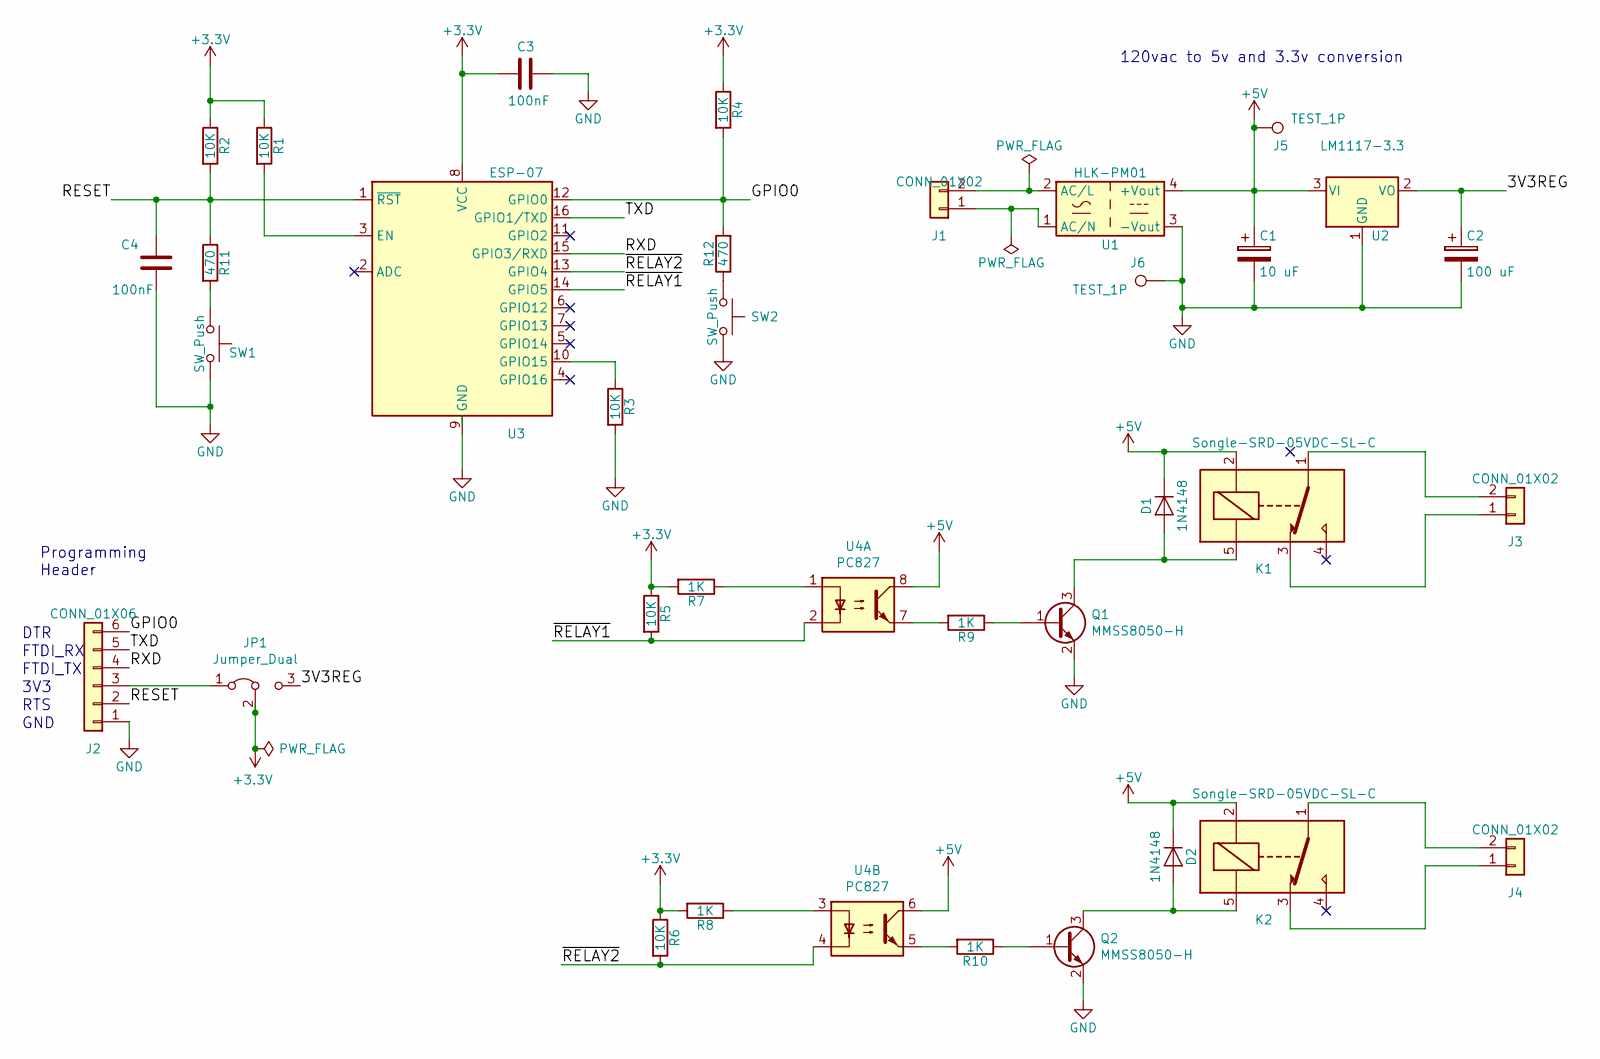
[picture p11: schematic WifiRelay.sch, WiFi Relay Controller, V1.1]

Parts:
C1: 10 uF; CP_EIA-3216-18_Kemet-A; MPN 293D106X0010A2TE3
C2: 100 uF; CP_EIA-3528-21_Kemet-B; MPN TL8A0107M010C
C3: 100nF; C_0805_2012Metric; MPN C0805C104K8RACTU; Mouser 80-C0805C104K8R
C4: 100nF; C_0805; MPN C0805C104K8RACTU; Mouser 80-C0805C104K8R
D1, D2: 1N4148; D_SOD-123; MPN 1N4148W-7-F; Mouser Value
J1, J4: CONN_01X02; TerminalBlock_Phoenix_MKDS-1,5-2_1x02_P5.00mm_Horizontal; MPN OSTYC022150
J2: CONN_01X06; PinHeader_1x06_P2.54mm_Vertical; MPN None
J3: CONN_01X02; TerminalBlock_Pheonix_MKDS1.5-2pol; MPN OSTYC022150
J5, J6: TEST_1P; PinHeader_1x01_P2.54mm_Vertical
JP1: Jumper_Dual; PinHeader_1x03_P2.54mm_Vertical; MPN Value; Mouser Value
K1, K2: Songle-SRD-05VDC-SL-C; Relay_SPDT_SANYOU_SRD_Series_Form_C; MPN Value; Mouser Value
Q1, Q2: MMSS8050-H; SOT-23
R1, R2, R3, R4, R5, R6: 10K; R_0805_2012Metric; MPN CRG0805F10K; Mouser 279-CRG0805F10K/10
R7, R8: 1K; R_0805_2012Metric; MPN CRG0805F1K0; Mouser Value
R9, R10: 1K; R_0805_2012Metric; MPN CRG0805F1K0
R11, R12: 470; R_0805_2012Metric; MPN CRG0805F470R; Mouser Value
SW1, SW2: SW_Push; SW_SPST_TL3342; MPN B3U-1000P; Mouser Value
U1: HLK-PM01; MPN IRM-02-05; Mouser 709-IRM02-5
U2: LM1117-3.3; SOT-223-3_TabPin2; MPN LM1117MPX-3.3/NOPBCT-ND; Mouser Value
U3: ESP-07
U4: PC827; SOIC-8; MPN Value; Mouser Value

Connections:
+3V3: C3.2, JP1.2 (C), R1.1, R2.1, R4.1, R5.1, R6.1, R7.2, R8.2, U3.8 (VCC)
+5V: C1.1, D1.1 (K), D2.1 (K), J5.1, K1.2, K2.2, U1.4 (+Vout), U2.3 (VI), U4.6, U4.8
/3V3REG: C2.1, JP1.3 (B), U2.2 (VO)
/GPIO0: J2.6, R4.2, R12.2, U3.12 (GPIO0)
/RESET: C4.1, J2.2, R2.2, R11.1, U3.1 (~RST)
/RXD: J2.4, U3.15 (GPIO3/RXD)
/TXD: J2.5, U3.16 (GPIO1/TXD)
/~RELAY1: R5.2, U3.14 (GPIO5), U4.2
/~RELAY2: R6.2, U3.13 (GPIO4), U4.4
GND: C1.2, C2.2, C3.1, C4.2, J2.1, J6.1, Q1.2 (E), Q2.2 (E), R3.2, SW1.2, SW2.2, U1.3 (-Vout), U2.1 (GND), U3.9 (GND)
unnamed: D1.2 (A), K1.5, Q1.3 (C)
unnamed: D2.2 (A), K2.5, Q2.3 (C)
unnamed: J1.1, U1.1 (AC/N)
unnamed: J1.2, U1.2 (AC/L)
unnamed: J2.3, JP1.1 (A)
unnamed: J3.1, K1.3
unnamed: J3.2, K1.1
unnamed: J4.1, K2.3
unnamed: J4.2, K2.1
unnamed: Q1.1 (B), R9.1
unnamed: Q2.1 (B), R10.1
unnamed: R1.2, U3.3 (EN)
unnamed: R3.1, U3.10 (GPIO15)
unnamed: R7.1, U4.1
unnamed: R8.1, U4.3
unnamed: R9.2, U4.7
unnamed: R10.2, U4.5
unnamed: R11.2, SW1.1
unnamed: R12.1, SW2.1

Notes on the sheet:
3V3
RTS
FTDI_RX
FTDI_TX
DTR
GND
120vac to 5v and 3.3v conversion
Programming Header

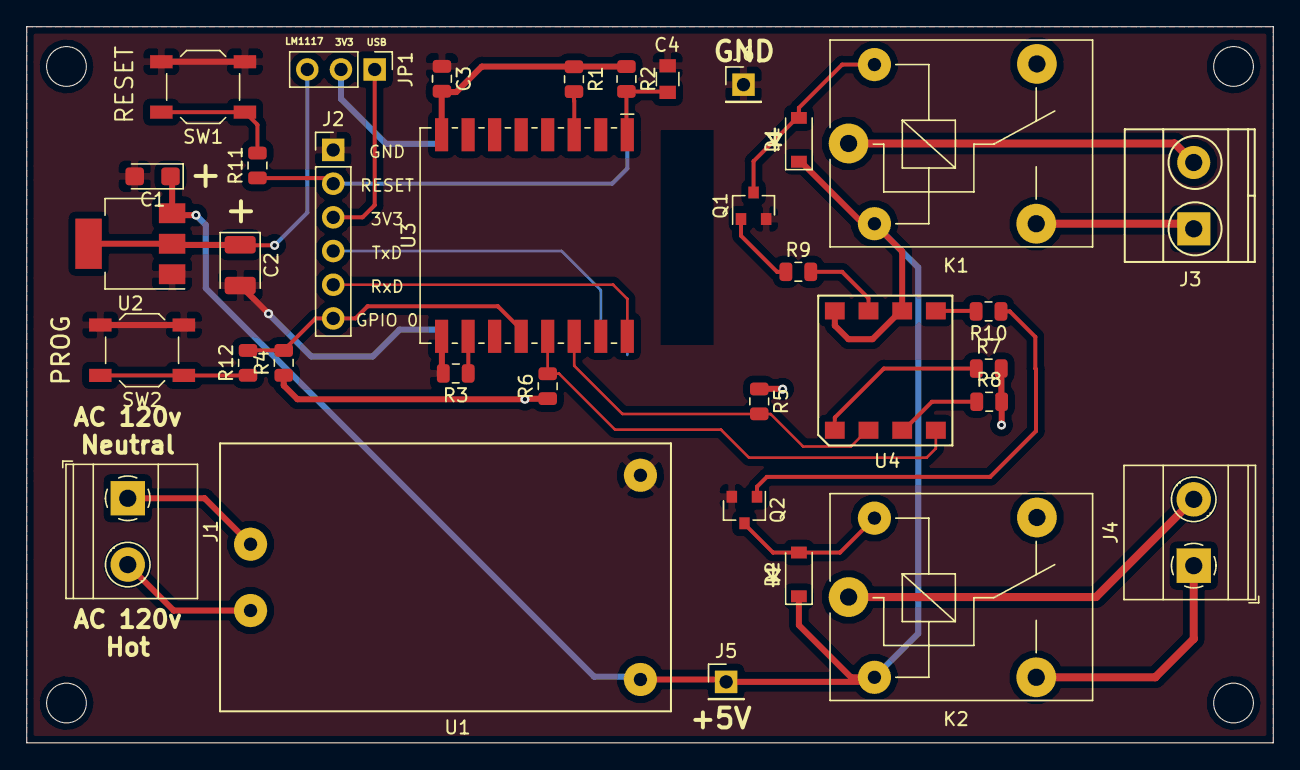
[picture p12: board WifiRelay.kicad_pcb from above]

Board: 2 copper layers, 94.0 x 54.0 mm, 35 parts (0 on the bottom side), 29 nets.

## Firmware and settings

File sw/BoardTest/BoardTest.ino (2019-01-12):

// Board test code for WiFi Pool Light controller board
// Turn on and off the relays in a "counting" sequence, e.g.
// 00 01 10 11 and repeat
// Simultaneously write action to serial output
// Allow control via MQTT to start/stop timers and set state of
// individual relays.

//Requires PubSubClient found here: https://github.com/knolleary/pubsubclient
#include <PubSubClient.h>
#include <ESP8266WiFi.h>
#include <SimpleTimer.h>
#include "Relay.h"

//EDIT THESE FILES TO MATCH YOUR SETUP
#include "PrivateWifi.h"
#include "PrivateMQTT.h"

#define RELAY_1_PIN 5          // This is NodeMCU D2
#define RELAY_2_PIN 4          // This is NodeMCU D1
#define PROG_SW 0              // GPIO 0 is the PROG switch
#define CYCLE_TIME  5000       // change state every 5000 milliseconds

void          mqtt_callback(char* topic, byte* payload, unsigned int length);
void          reconnect();
String        macToStr(const uint8_t* mac);

WiFiClient    wifiClient;
PubSubClient  client(wifiClient);
SimpleTimer   timer;
MQTT_Relay    Relay_1(RELAY_1_PIN, "Relay 1", "test/Relay1", &timer);
MQTT_Relay    Relay_2(RELAY_2_PIN, "Relay 2", "test/Relay2", &timer);
const char*   relayTopic = "test/#";
int           bFirstPass = true;

void setup() {

  int bStep = 1;

  //start the serial line for debugging
  Serial.begin(115200);
  delay(100);
  Relay_1.StartTimer(CYCLE_TIME);
  Relay_1.Disable();
  Relay_2.StartTimer(CYCLE_TIME * 2);
  Relay_2.Disable();

  Serial.println("Starting WiFi Relay v1.1 Board Test");

  // Set up and read PROG_SW
  pinMode(PROG_SW, INPUT);
  bStep = digitalRead(PROG_SW);
  if (bStep == HIGH)
    Serial.println("PROG switch is not pressed.");
  else
    Serial.println("PROG switch is pressed.");

  Serial.println("Relay 1 should be OPEN");
  Serial.println("Relay 2 should be OPEN");

  //attempt to connect to the WIFI network and then connect to the MQTT server
  //start wifi subsystem
  WiFi.begin(WIFI_SSID, WIFI_PW);
  //wait a bit before starting the main loop
  delay(2000);
  //reconnect();
}

void loop(){

  int bStep = HIGH;
  int pushTime = 0;

  if (bFirstPass) {
    bFirstPass = false;
    do {
      while (bStep == HIGH) {
        timer.run();
        client.loop();
        delay(10);
        bStep = digitalRead(PROG_SW);
      };
      // Falls through when PROG button pushed
      pushTime = millis();
      while (bStep == LOW) {
        timer.run();
        client.loop();
        delay(10);
        bStep = digitalRead(PROG_SW);
      };
      // falls through when PROG button released
      if (millis() - pushTime < 1500) {
        Relay_1.Toggle();
        if (Relay_1.IsOn()) {
          Relay_2.Off();
          Serial.println("Relay 1 On");
          Serial.println("Relay 2 Off");
        }
        else {
          Relay_2.On();
          Serial.println("Relay 1 Off");
          Serial.println("Relay 2 On");
        };
      };
    } while (millis() - pushTime < 1500);
    reconnect();
  };
  //reconnect if connection is lost
  if (!client.connected() && WiFi.status() == 3) {reconnect();}

  timer.run();

  //maintain MQTT connection
  client.loop();

  //MUST delay to allow ESP8266 WIFI functions to run
  delay(20); 
}

void mqtt_callback(char* topic, byte* payload, unsigned int length) {

  //convert topic to string to make it easier to work with
  String topicStr = topic;
  String strPayload;
  for (int i = 0; i < length; ++i)
  {
    strPayload += (char)payload[i];
  }

  //Print out some debugging info
  Serial.print("Callback update...");
  Serial.print("Topic: ");
  Serial.println(topicStr);

  if (Relay_1.HandleMQTT(topicStr, strPayload))
  {
    Serial.println(Relay_1.getStringStatus());
  }
  if (Relay_2.HandleMQTT(topicStr, strPayload))
  {
    Serial.println(Relay_2.getStringStatus());
  }
  if (topicStr == "test/Timer")
  {
    if (strPayload == "Disable")
    {
//      timer.disable(TimerId);
      Serial.println("Timer Disabled");
    }
    if (strPayload == "Enable")
    {
//      timer.enable(TimerId);
      Serial.println("Timer Enabled");
    }
    if (strPayload == "Toggle")
    {
 //     timer.toggle(TimerId);
      Serial.println("Timer Toggled");
    }
  }

  //turn the light on if the payload is '1' and publish to the MQTT server a confirmation message
  if(payload[0] == '1'){
    Relay_1.On();
    client.publish("/test/confirm", "1");
  }

  //turn the light off if the payload is '0' and publish to the MQTT server a confirmation message
  else if (payload[0] == '0'){
    Relay_1.Off();
    client.publish("/test/confirm", "0");
  }
}
void reconnect() {

  //attempt to connect to the wifi if connection is lost
  if(WiFi.status() != WL_CONNECTED){
    //debug printing
    Serial.print("\nConnecting to ");
    Serial.println(WIFI_SSID);

    //loop while we wait for connection
    while (WiFi.status() != WL_CONNECTED) {
      delay(500);
      Serial.print(".");
    }

    //print out some more debug once connected
    Serial.println("");
    Serial.println("WiFi connected");  
    Serial.println("IP address: ");
    Serial.println(WiFi.localIP());
  }

  client.setServer(MQTT_SERVER, MQTT_PORT);
  client.setCallback(mqtt_callback);

  //make sure we are connected to WIFI before attemping to reconnect to MQTT
  if(WiFi.status() == WL_CONNECTED){
  // Loop until we're reconnected to the MQTT server
    while (!client.connected()) {
      Serial.print("Attempting MQTT connection...");

      // Generate client name based on MAC address and last 8 bits of microsecond counter
      String clientName;
      clientName += "esp8266-";
      uint8_t mac[6];
      WiFi.macAddress(mac);
      clientName += macToStr(mac);

      //if connected, subscribe to the topic(s) we want to be notified about
      if (client.connect((char*) clientName.c_str(), MQTT_USER, MQTT_PW)) {
        Serial.println("\tMQTT Connected");
        client.subscribe(relayTopic);
      }

      //otherwise print failed for debugging
      else{
        Serial.println("\tFailed."); 
        abort();
      }
    }
  }
}

//generate unique name from MAC addr
String macToStr(const uint8_t* mac){

  String result;

  for (int i = 0; i < 6; ++i) {
    result += String(mac[i], 16);

    if (i < 5){
      result += ':';
    }
  }

  return result;
}

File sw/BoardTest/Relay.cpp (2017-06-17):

#include "Relay.h"

// Constructor
Relay::Relay(int Pin, String strName) : relayPin(Pin), relayName(strName), relayState(RELAY_OFF)
{
  pinMode(relayPin, OUTPUT);
  digitalWrite(relayPin, RELAY_OFF);
}

void Relay::Off()
{
  digitalWrite(relayPin, RELAY_OFF);
  relayState = RELAY_OFF;
}
void Relay::On()
{
  digitalWrite(relayPin, RELAY_ON);
  relayState = RELAY_ON;
}
void Relay::Toggle()
{
  if ( IsOn() ) {
    Off();
  }
  else {
    On();
  }
}

String& Relay::Id()
{
  return relayName;
}

String Relay::getStringStatus() {
  String tmp = relayName;
  if (relayState == RELAY_ON)
    tmp += " =  ON";
  else
    tmp += " = OFF";
  return tmp;
}

bool Relay::IsOn() {
  return relayState == RELAY_ON;
}

MQTT_Relay::MQTT_Relay(int    Pin, 
                       String strName, 
                       String Topic,
                       SimpleTimer *pTimer) 
  : Relay(Pin, strName),  strTopic(Topic), Timer(pTimer)
{
}

bool MQTT_Relay::HandleMQTT(String& Topic, String& Payload)
{
  bool rc = false;
  if (Topic == strTopic)
  {
    rc = true;
    if (Payload == "On")
      On();
    if (Payload == "Off")
      Off();
    if (Payload == "Toggle")
      Toggle();
    if (Payload == "Disable")
    {
      Timer->disable(TimerId);
      Serial.println("Timer Disabled");
    }
    if (Payload == "Enable")
    {
      Timer->enable(TimerId);
      Serial.println("Timer Enabled");
    }
  }
  return rc;
}

void MQTT_Relay::TimerCallback()
{
  Toggle();
  Serial.println(getStringStatus() + " , Uptime: " + millis()/1000);
}

bool MQTT_Relay::StartTimer(int Interval)
{
  if (Timer)
  {
    TimerId = Timer->setInterval(Interval, std::bind(&MQTT_Relay::TimerCallback, this));
    return true;
  }
  else
  {
    Serial.println("No timer defined");
    return false;
  }
}

void MQTT_Relay::Disable()
{
  Timer->disable(TimerId);
} 


void MQTT_Relay::Enable()
{
  Timer->enable(TimerId);
} 

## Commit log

2017-05-03 Initial file upload
    [Pool Lights-B.Cu.gbl, Pool Lights-B.Mask.gbs, Pool Lights-B.SilkS.gbo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]
2017-05-09 Added ESP libraries
    [Pool Lights.sch]
2017-05-25 Renamed from 'Pool Lights' to WifiRelay' and added template for drilling the box
    [WifiRelay.kicad_pcb, WifiRelay.sch]
2017-06-01 V1.1 hardware with low cost components Dropped LEDs Added +5v test point Changed two single optos for 1 dual Changed relay, +5v AC/DC conv, and 100uF parts footprints
    [Pool Lights-B.Cu.gbl, Pool Lights-B.Mask.gbs, Pool Lights-B.SilkS.gbo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]
2017-06-17 Updates to board test, schematic title block, 3D models
    [WifiRelay.kicad_pcb, WifiRelay.sch]
2017-07-04 Silkscreen updates to programming header, changed 3.3v power jumper to two positions
    [WifiRelay-B.Cu.gbl, WifiRelay-B.Mask.gbs, WifiRelay-B.SilkS.gbo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]
2017-08-16 Update README.md
    Corrected to reflect use of ESP-07 with both onboard and external antenna
2017-08-23 Readable schematic
2018-02-20 Adding kicad libraries
2018-12-26 Update for consistency with KiCad 5.02
    [WifiRelay-2018-12-25-09-27-47.sch, WifiRelay.sch]
2018-12-29 Revert "Bring SimpleTimer library into tracked code"
    This reverts commit 778c7b7149f805f02c32ed545d85f82c4505fd21.
    [BoardTest.ino]
2019-01-07 Fixed lint / compiler gripe with const char *
    [BoardTest.ino]
2019-01-12 Adjusted library paths Remapped symbols to legacy libraries for KiCad 5 compatibility
    [WifiRelay.sch]
2019-01-12 Changes to improve version comparisons in KiCad See https://jnavila.github.io/plotkicadsch/
2019-01-12 Reverted WifiRelay.sch
    [WifiRelay.sch]
2019-01-12 Changed to Unix line endings
    [WifiRelay.sch]
2019-01-12 Remapped symbols into V5 libraries
    [WifiRelay.sch]
2019-01-12 Unix line endings
    [WifiRelay.sch]
2019-01-12 Added build notes and a batch file to flash BoardTest
2019-01-13 Updated symbol and footprint libraries to use KiCad 5 versions.
    [WifiRelay.kicad_pcb, WifiRelay.sch, WifiRelay.xlsx]
2019-01-13 Updated symbol for MMSS8050-H transistor to use new KiCad library symbol
    [WifiRelay.kicad_pcb, WifiRelay.sch, WifiRelay.xlsx]
2019-01-13 Added 3D shape for relays
    [WifiRelay.kicad_pcb]
2019-01-13 Added 3D shapes for 2 pin terminal blocks J1, J3 and J4
    [WifiRelay.kicad_pcb]
2019-01-13 Added 3D symbol for ESP-07. Corrected connections to J1 and J4 (broken in previous revision)
    [WifiRelay.kicad_pcb]
2019-01-13 Added datasheet for LM1117-3.3
    [WifiRelay.sch]
